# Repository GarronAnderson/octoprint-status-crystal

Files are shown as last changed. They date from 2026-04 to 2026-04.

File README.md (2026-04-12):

# octoprint-status-crystal
### A 3D-printed status lamp for your octoprint-enabled printer

This lamp shows your printer's status and connects via the Octoprint API. It has a LDR for automatic brightness sensing.

The STL files are adapted from [this Printables link.](https://www.printables.com/model/412168-subtle-color-changing-crystals)

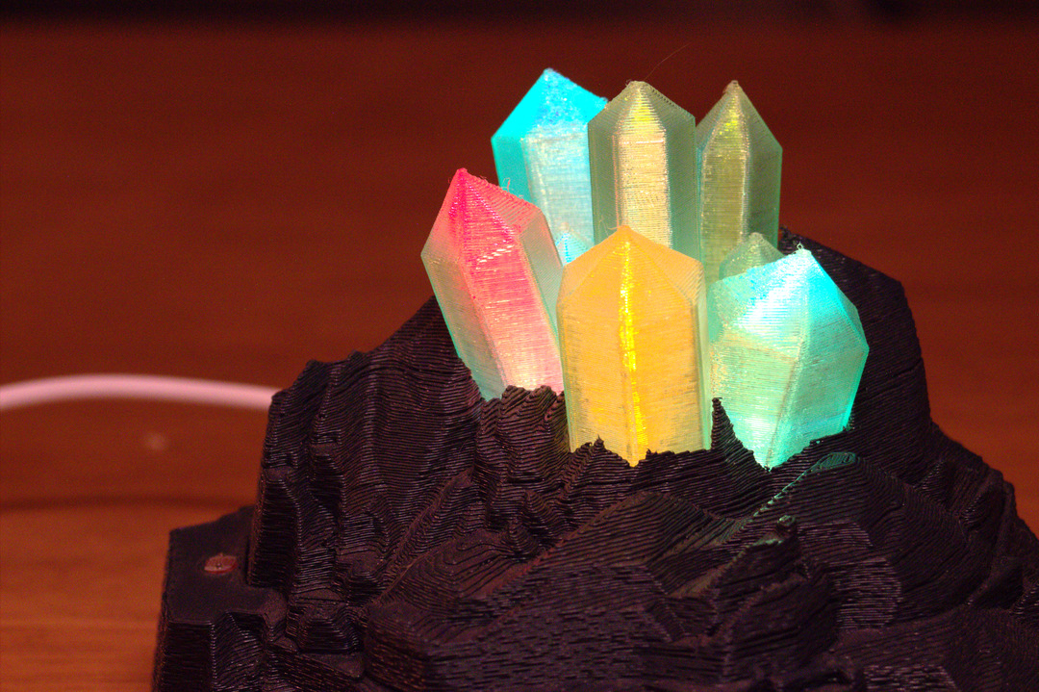
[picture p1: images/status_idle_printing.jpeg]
The crystal in an idle state


## Printing

The STLs were printed on a Prusa i3. The two rock bases were printed in Prusament Gentleman's Gray PLA, and the crystals in translucent Prusament Neon Green PETG.

Layer height was 0.2 mm. Models were printed with the Fuzzy Skin effect on the sides to make them look more natural.

## Assembly

My lamp runs on a Raspberry Pi Pico W (you could use another microcontroller, as long as it has WiFi). It is powered over USB through the cutout in the base (I did have to shave down the micro USB cable). There are 6 differently colored LEDs attached to the Pico.

The cutout in the side of the crystal is for a LDR. It is hooked up as a voltage divider with a 10k resistor.

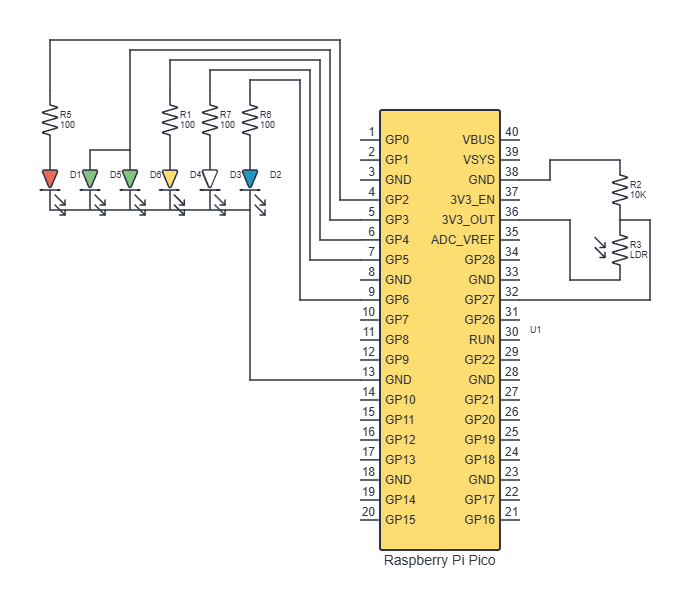
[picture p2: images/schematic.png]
The schematic of the circuit


The LEDs press fit into the bottom of the crystal. Two of the openings are not used.

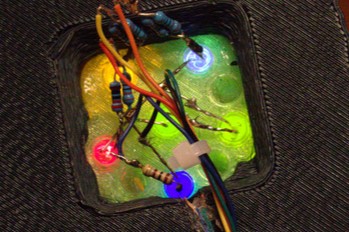
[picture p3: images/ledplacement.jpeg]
LED placement diagram


## Programming

Place code.py in the root of your CircuitPython device.
Copy the /lib folder to the /lib folder of your device.

Rename example_settings.toml to settings.toml and update the WiFi info and Octoprint API key for your printer.

There are various settings that can be tweaked in code.py under `USER INPUT AND SETUP`.

Depending on your LEDs, room brightness, etc. you may need to tweak the `BRIGHTNESS_THRESHOLD` for the light/dark changeover.

If your printer is not at `http://octoprint.local` you will need to change `OCTOPRINT_URL`.

## Modes

The lamp has 8 different modes: Idle, Printing, Finished, Heating, Cooling, Error, Paused and Connection Error. In most of the modes, the LEDs have a subtle pulsing animation.

The error sensing is done by reading the Octoprint status, but that is not always reliable. For example, a MMU filament error doesn't change the reported status, the print time just doesn't update. So, the lamp watches the remaining print time, and if it stops updating, the status is set to Error.

When the print finishes, the LEDs pulse fast for 5 minutes (can be changed in code.py) to indicate that the print is done!

### Idle

All LEDs on

### Finished

All LEDs pulsing

### Printing

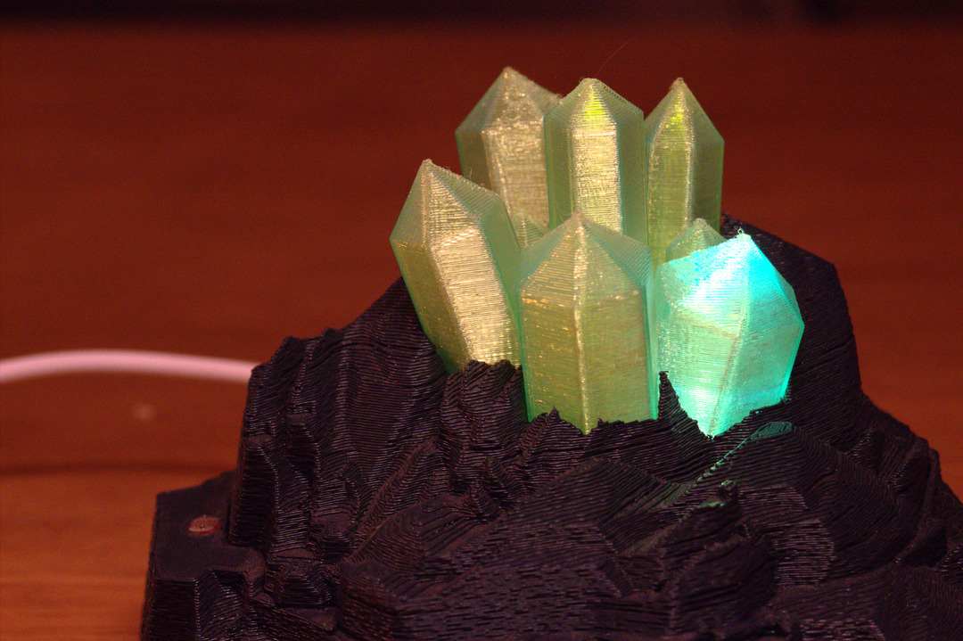
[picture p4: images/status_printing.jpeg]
Green and White on


### Heating

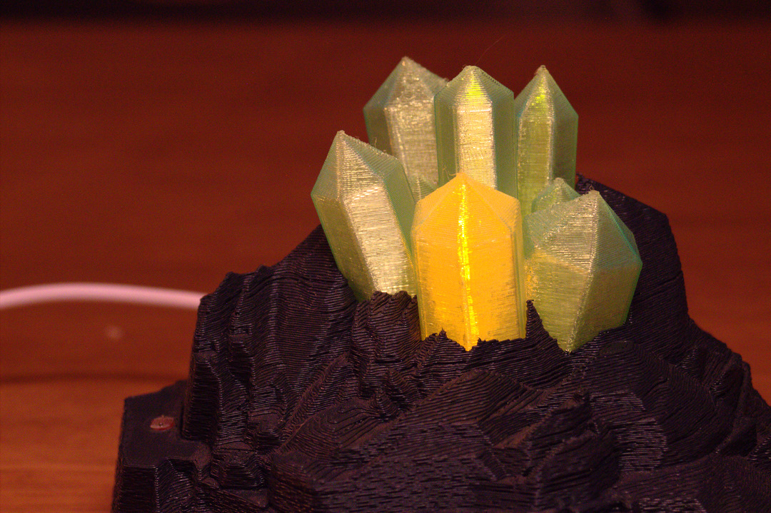
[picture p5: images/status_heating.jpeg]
Green and Yellow on


### Cooling

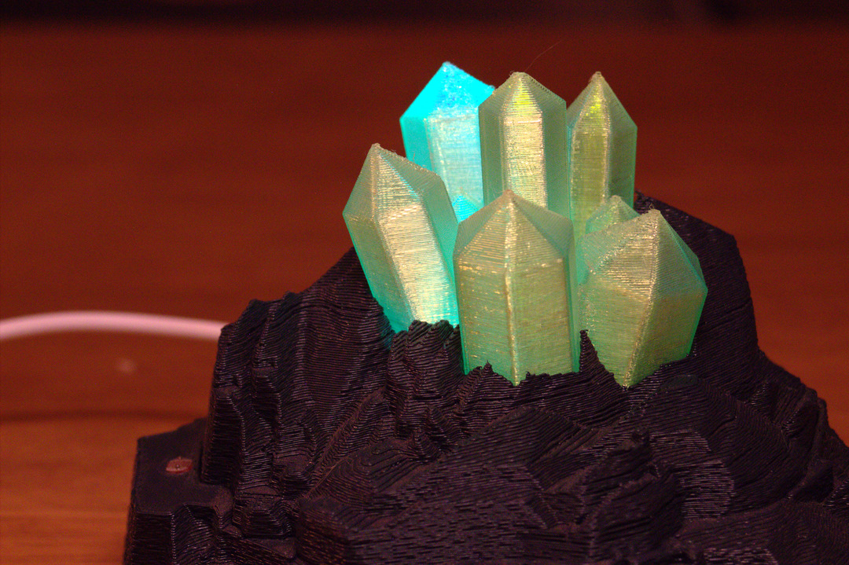
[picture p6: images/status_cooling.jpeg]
Green and Blue on


### Error

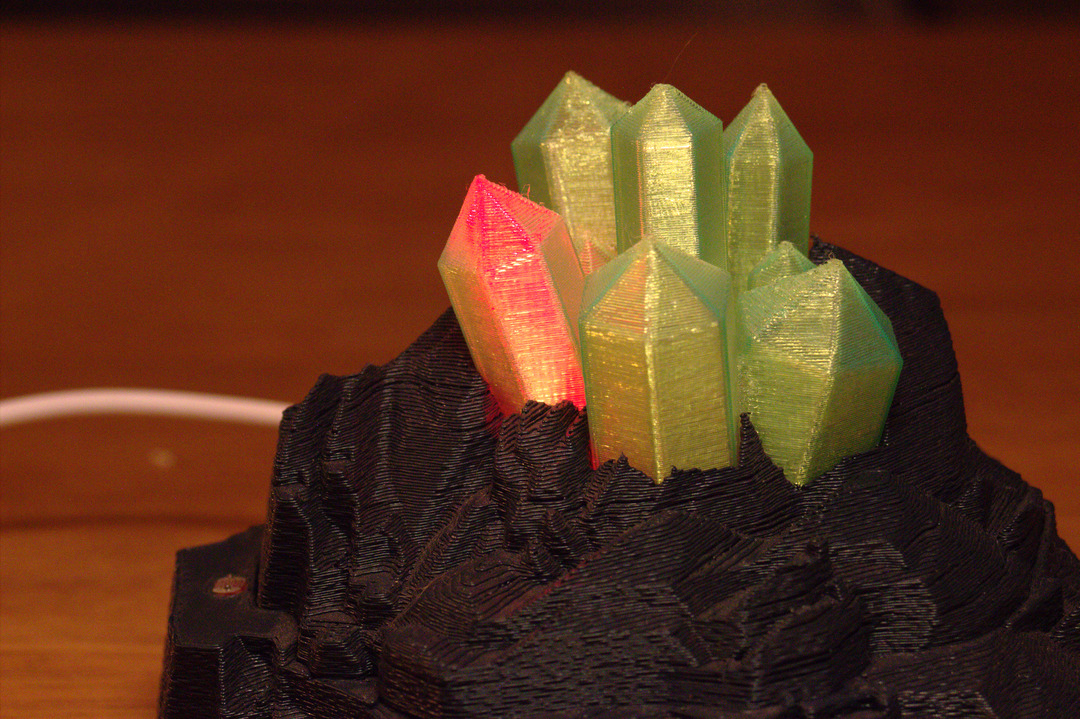
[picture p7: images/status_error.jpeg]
Red on


### Connection Error

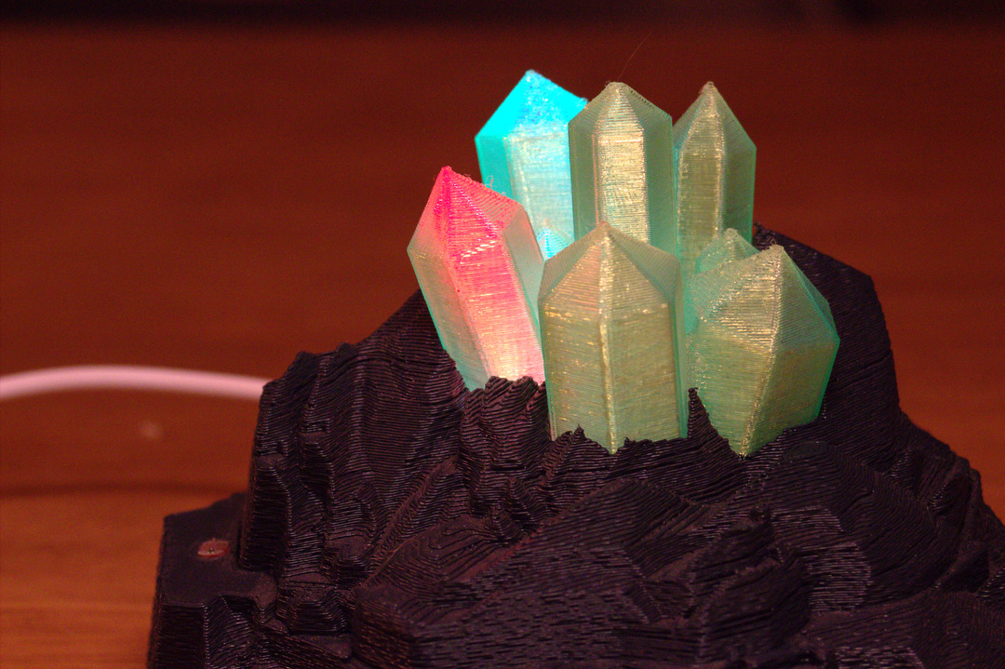
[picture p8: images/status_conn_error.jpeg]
Red and Blue on


### Paused

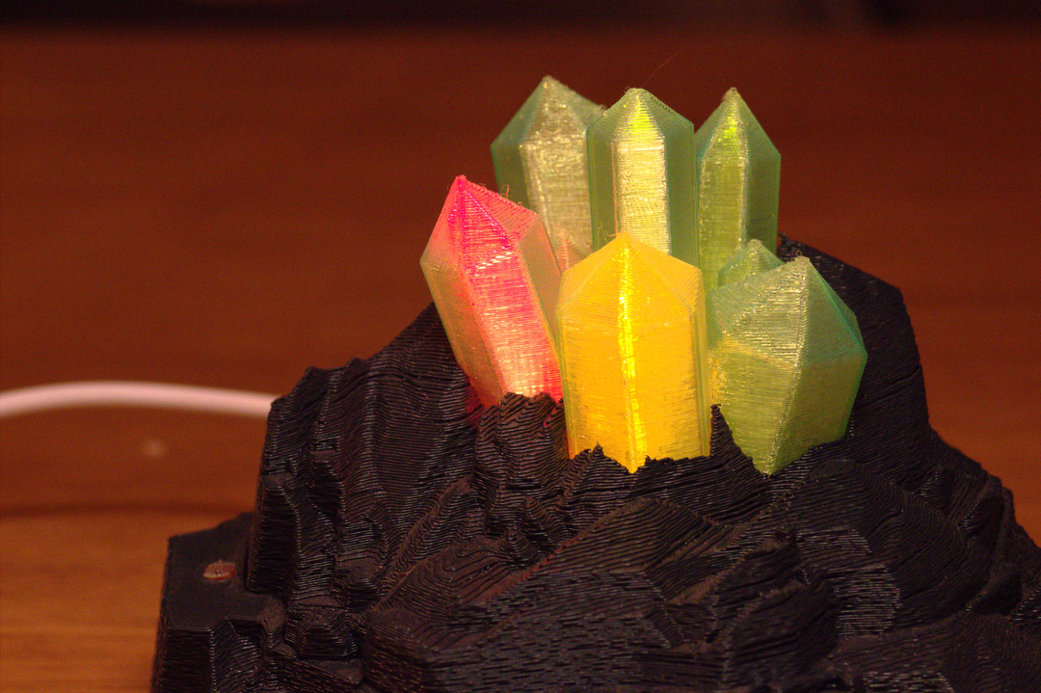
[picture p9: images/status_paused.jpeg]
Yellow and Red on


## Automatic Brightness Adjustment

The lamp switches Brightness

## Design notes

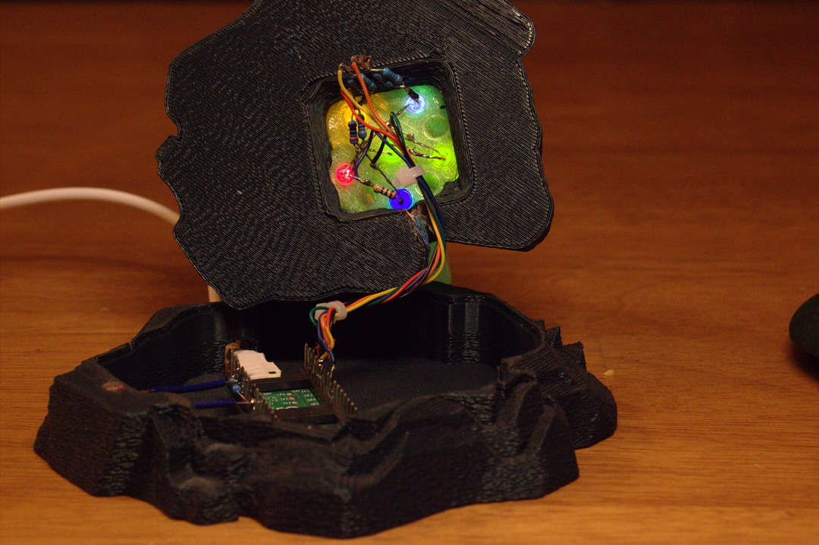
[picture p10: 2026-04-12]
images/inside.jpeg

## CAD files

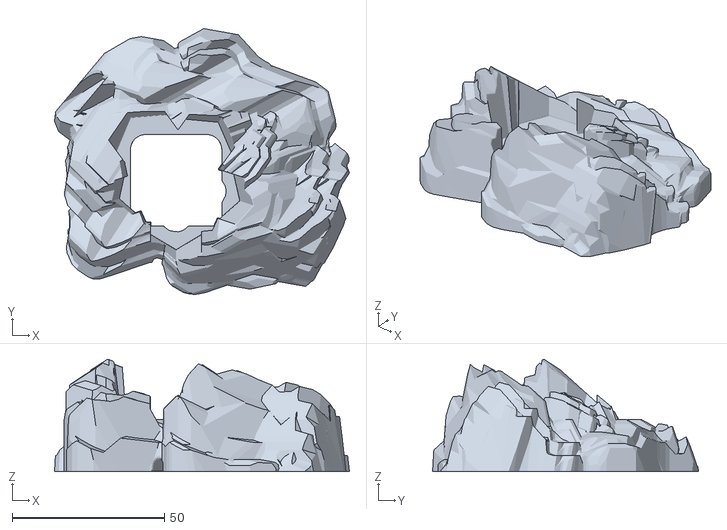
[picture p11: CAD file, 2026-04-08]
STLs/Rock Base Top Section.stl
96.8 x 87.3 x 36.8

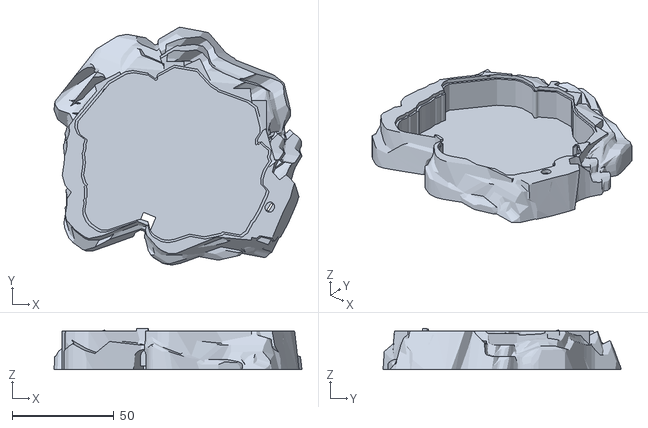
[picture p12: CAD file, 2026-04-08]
STLs/Rock Base Bottom Section.stl
122.0 x 117.1 x 20.3

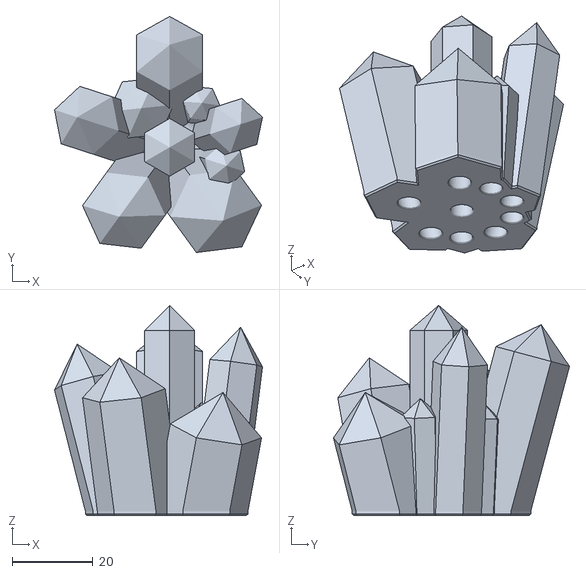
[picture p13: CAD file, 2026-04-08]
STLs/Crystal Insert.stl
51.6 x 58.6 x 52.2

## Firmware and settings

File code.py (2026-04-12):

# Octoprint Status Lamp Controller
# Garron Anderson, 2025


import os
import random
import time

import adafruit_connection_manager
import adafruit_requests
import board
import pwmio
import wifi
from analogio import AnalogIn

from EzLED import LED

# === USER INPUT AND SETUP ===

POLL_FREQUENCY = 10  # seconds

BRIGHT_MAX = 255  # 0 to 255
BRIGHT_MIN = 100

DIM_MAX = 100
DIM_MIN = 40

BRIGHTNESS_THRESHOLD = 0.3  # from 0 (dark) to 1 (bright)

TEMP_TOLERANCE = 5  # deg C, if you're within this number, you're at temperature

ROOM_TEMP = 50  # deg C, if you're under this, you're done cooling

FINISHED_TIMER = 5  # minutes, how long to indicate finished for
ERROR_DURATION = 60  # seconds, if the print_time_left doesn't change for this long, assume we're stuck

OCTOPRINT_URL = "http://octoprint.local"

# === END USER INPUT ===

_time_print_finished = 0
_was_printing = False
_last_print_time_left = 0
_error_counter = 0


def get_status():
    """Get printer status.

    Gets the status of the printer from OctoPrint.

    Args:
        None.

    Returns:
        str: The status as a string (this avoids magic numbers).
    """
    global _time_print_finished, _was_printing, _last_print_time_left, _error_counter

    try:
        with requests.get(
            OCTOPRINT_URL + "/api/printer",
            headers={"X-Api-Key": os.getenv("OCTOPRINT_API_KEY")},
        ) as printer_request:
            status = printer_request.json()
            try:
                status_flags = status["state"]["flags"]
            except KeyError:  # this means we're in an error state
                return ERROR
    except Exception as e:
        if e.errno == -2:  # it's a gaierror, we can't find the printer
            return CONN_ERROR
        else:
            raise e  # go ahead and crash

    with requests.get(
        OCTOPRINT_URL + "/api/job",
        headers={"X-Api-Key": os.getenv("OCTOPRINT_API_KEY")},
    ) as job_request:
        job_status = job_request.json()

    if (
        status_flags.get("error")
        or status_flags.get("cancelling")
        or status_flags.get("closedOrError")
    ):
        return ERROR

    if status_flags.get("paused") or status_flags.get("pausing"):
        return PAUSED

    if status_flags.get("operational"):
        # okay, we're not in an error or paused
        # so check heat/cool
        temp_target = status["temperature"]["tool0"]["target"]
        temp_now = status["temperature"]["tool0"]["actual"]

        if (_was_printing and not status_flags.get("printing")) or (
            status_flags.get("finishing")
        ):
            # we were printing, and now we're not, so therefore set the finished timer
            _was_printing = False
            _time_print_finished = time.time()

        if _time_print_finished and (time.time() - _time_print_finished) < (
            FINISHED_TIMER * 60
        ):  # but first check the timer
            # just finished a print
            return FINISHED

        # cooling is a target of 0 and temperature greater than ROOM_TEMP
        if temp_target == 0 and temp_now > ROOM_TEMP:
            return COOLING
        # heating is printing status, but with an unmet temperature tolerance
        if (temp_target != 0 and temp_now > ROOM_TEMP) and abs(
            temp_now - temp_target
        ) > TEMP_TOLERANCE:
            return HEATING

        if (
            _time_print_finished
            and (time.time() - _time_print_finished) < FINISHED_TIMER
        ):
            # just finished a print
            return FINISHED

        if status_flags.get("printing"):
            # we aren't errored, heating, or cooling, so must be printing
            _was_printing = True
            # but if remaining print time didn't change for 30 secs, we're errored
            print_time_left = job_status["progress"]["printTimeLeft"]
            if _last_print_time_left == print_time_left:
                _error_counter = _error_counter + 1
                # so we bumped the error counter up, did we hit threshold?
                if _error_counter >= (ERROR_DURATION // POLL_FREQUENCY):
                    return ERROR  # we hit threshold, error
                else:  # we're still printing
                    return PRINTING
            else:  # the print time moved
                _error_counter = 0
                _last_print_time_left = print_time_left
                return PRINTING

        # nothing exciting happened
        return IDLE


# LED Setup

raw_red = pwmio.PWMOut(board.GP2)
raw_grn = pwmio.PWMOut(board.GP3)
raw_ylw = pwmio.PWMOut(board.GP4)
raw_wht = pwmio.PWMOut(board.GP5)
raw_blu = pwmio.PWMOut(board.GP6)

raw_LEDs = [raw_red, raw_grn, raw_ylw, raw_wht, raw_blu]

for led in raw_LEDs:
    led.duty_cycle = 0

red = LED(raw_red)
grn = LED(raw_grn)
ylw = LED(raw_ylw)
wht = LED(raw_wht)
blu = LED(raw_blu)

LEDs = [red, grn, wht, ylw, blu]

for led in LEDs:
    led.b_max = BRIGHT_MAX
    led.b_min = BRIGHT_MIN
    led.period = 5 + random.uniform(0, 0.4)

grn.b_max = 255
grn.b_min = 50

light_sensor = AnalogIn(board.A1)

# WiFi setup
try:
    wifi.radio.connect(
        ssid=os.getenv("CIRCUITPY_WIFI_SSID"),
        password=os.getenv("CIRCUITPY_WIFI_PASSWORD"),
    )

    pool = adafruit_connection_manager.get_radio_socketpool(wifi.radio)
    requests = adafruit_requests.Session(pool)
except:
    for led in LEDs:
        led.off()
    red.pulse(period=0.5)
    blu.pulse(period=0.5)
    last_led = time.monotonic()
    while True:
        # update LED animations
        time_now = time.monotonic()
        dt = time_now - last_led
        for led in LEDs:
            led.update(dt)
        last_led = time_now

# Modes
BRIGHT = "BRIGHT"
DIM = "DIM"

IDLE = "IDLE"
ERROR = "ERROR"
CONN_ERROR = "CONN_ERROR"
PAUSED = "PAUSED"
PRINTING = "PRINTING"
HEATING = "HEATING"
COOLING = "COOLING"
FINISHED = "FINISHED"

last_poll = 0
last_led = time.monotonic()

# set initial status
brightness = BRIGHT
status = IDLE
new_status = IDLE

mode = 0

while True:
    if (time.monotonic() - last_poll) > POLL_FREQUENCY:  # poll octoprint
        last_poll = time.monotonic()
        new_status = get_status()

    # update LED animations
    time_now = time.monotonic()
    dt = time_now - last_led

    dt = min(
        dt, 0.05
    )  # without this, an OctoPrint check would cause a large dt, making the brightness jump. Bit hacky but works.

    for led in LEDs:
        led.update(dt)
    last_led = time_now

    # update LED brightness
    brightness_reading = light_sensor.value / 65536
    if brightness_reading > BRIGHTNESS_THRESHOLD:  # bright mode
        new_brightness = BRIGHT
    else:
        new_brightness = DIM

    if new_brightness != brightness:
        print(f"resetting brightness to {new_brightness}")
        for led in LEDs:
            if new_brightness == BRIGHT:
                led.b_max = BRIGHT_MAX
                led.b_min = BRIGHT_MIN
            else:
                led.b_max = DIM_MAX
                led.b_min = DIM_MIN
            # green gets an override
            grn.b_max = 255
            grn.b_min = 50

        brightness = new_brightness

    # update LED colors
    status_changed = status != new_status
    if status_changed:
        print(f"printer status changed to {new_status}")
        if new_status == IDLE:
            for led in LEDs:
                led.pulse(period=5 + random.uniform(0, 0.4))

        elif new_status == ERROR:
            for led in LEDs:
                led.off()
            red.pulse(period=2)

        elif new_status == CONN_ERROR:
            for led in LEDs:
                led.off()
            red.pulse(period=2)
            blu.pulse(period=1.9)

        elif new_status == PRINTING:
            for led in LEDs:
                led.off()
            grn.on()
            wht.pulse(period=3)

        elif new_status == HEATING:
            for led in LEDs:
                led.off()
            grn.on()
            ylw.pulse(period=3)

        elif new_status == COOLING:
            for led in LEDs:
                led.off()
            grn.on()
            blu.pulse(period=3)

        elif new_status == FINISHED:
            for led in LEDs:
                led.pulse(period=0.5 + random.uniform(0, 0.5))

        elif new_status == PAUSED:
            for led in LEDs:
                led.off()
            red.pulse(period=2)
            ylw.pulse(period=2)

        status = new_status

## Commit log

2026-04-08 python refactoring and maintenance, add STLs
    added the STLs for printing
    worked on README
    ran black over code
    fixed example_settings.toml
    [Crystal Insert.stl, Rock Base Bottom Section.stl, Rock Base Top Section.stl]
2026-04-12 move files to CircuitPython lib
    moved some files to the CircuitPython lib directory and updated .gitignore to include them
